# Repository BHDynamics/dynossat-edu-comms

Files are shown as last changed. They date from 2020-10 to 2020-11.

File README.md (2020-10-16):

# DynOSSAT-EDU-Comms (Communications System)
DynOSSAT-EDU is the first open source PocketQube educational kit compatible with CircuitPython and Arduino.

This plaform is equipped with all the necessary modules for the operation of a nanosatellite (PocketQube)
in Low Earth Orbit (LEO) that would serve as a device for teaching, training, and driving curiosity about the philosophy and technology related to NewSpace.

This repository contains the hardware files for the Communications system, the module responsible for handling radio communications.It integrates a long range LoRa module
to simulate LEO-Earth communications and a 2.4 GHz nRF52832 SoC to simulate LEO-LEO communications and to allow communication with mobile apps for teaching and simulation projects using Smartphones.

Hardware in this repository is licenced under **CERN OHL v1.2**.

## Technical details

- Based on HopeRF’s RFM96W 868 MHz LoRa module, pad-to-pad compatible with the 433 MHz RFM95W version
- Easily controlled through SPI bus
- Secondary 2.4 GHz SoC (SKB369) based on Nordic Semi nRF52832 that can act as an independent or redundant processor through I2C or SPI
- Female USB-C 2.0 connector for power and data logging (CH340E USB to UART bridge)

## Documentation

Available soon!

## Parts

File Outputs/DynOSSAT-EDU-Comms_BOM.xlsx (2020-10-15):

Item | Qty | Reference(s) | Value | Part Number | Footprint
1 | 2 | C1, C3 | 10uF |  | 0603 10uF X7R/X5R 10V or greater
2 | 3 | C2, C4, C8 | 100nF |  | 0402 100nF X7R/X5R 10V or greater
3 | 2 | C5, C6 | DNP | -
4 | 1 | D1 | LED | Device:LED | 0603 LED Red
5 | 1 | J1 | Main Bus PQBH40 | We don't have part numbers. Use generic connectors | Pin header male 1.27mm pitch 2x20 vertical SMD
6 | 1 | J2 | Main Bus PQBH40 | We don't have part numbers. Use generic connectors | Pin socket female 1.27mm pitch 2x20 vertical SMD
7 | 1 | J4 | Conn_Coaxial | U.FL-R-SMT-1(80) | 50 ohm U.FL Coaxial Connector
8 | 1 | J5 | USB_C_Receptacle_USB2.0 | U262-161N-4BVC11 | USB-C 2.0 connector - female socket
9 | 1 | J7 | Conn_01x09_Female | We don't have part numbers. Use generic connectors | Pin header male 2.54mm pitch 1x09 vertican Through Hole
10 | 1 | L1 | 0R |  | 0 ohm resistor 0402
11 | 2 | Q1, Q2 | DMG2305L | DMG2305UX-7 | P-Channel Power Mosfet
12 | 3 | R1, R5, R7 | 100k |  | 0402 100k 1%
13 | 2 | R2, R3 | 47k |  | 0402 47k 1%
14 | 2 | R4, R6 | 5.1k |  | 0402 5.1k 1%
15 | 1 | R8 | 510R |  | 0402 510R 1%
16 | 1 | SW1 | SW_Push | 1TS002G-1800-3500-CT | Push Button side mount
17 | 1 | U1 | ME6211C33 | ME6211C33M5G-N | 3V3 LDO SOT-23-5
18 | 1 | U2 | HopeRF RFM95 | RFM95W | 868 MHz LoRA module - global version
19 | 1 | U3 | Skylab SKB369 | SKB369 | Bluetooth Low Energy Module
20 | 1 | U4 | CH340E | CH340E | USB to UART Bridge IC SOIC-8
For passives (resistors, capacitors, etc) you may use any quality brand while meeting requirements

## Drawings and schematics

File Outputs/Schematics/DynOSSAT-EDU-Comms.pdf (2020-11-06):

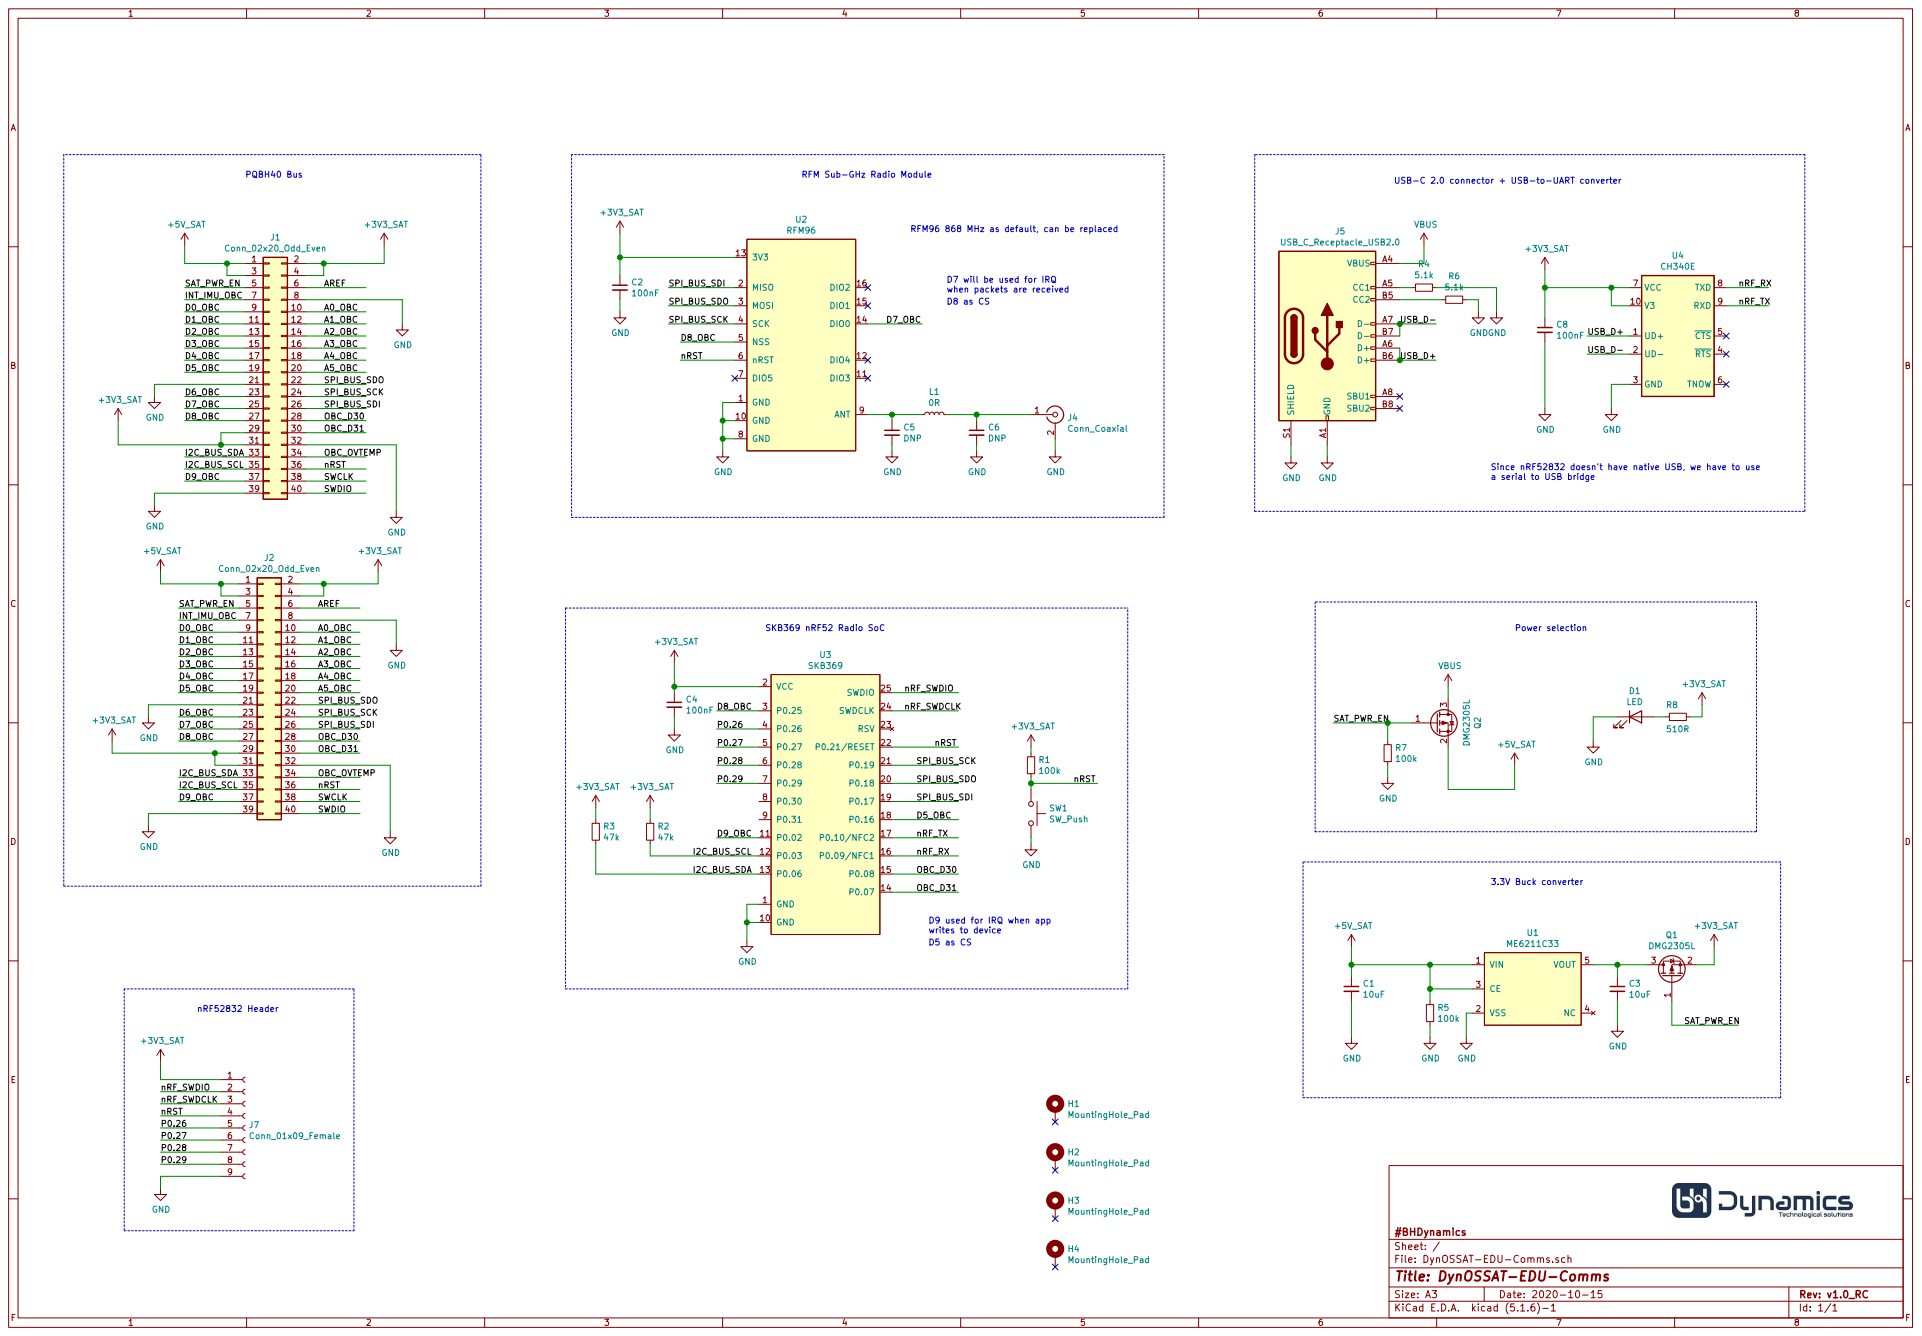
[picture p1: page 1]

USB-C 2.0 connector + USB-to-UART converter PQBH40 Bus

RFM96 868 MHz as default, can be replaced RFM Sub-GHz Radio Module SKB369 nRF52 Radio SoC

D7 will be used for IRQ
when packets are received
a serial to USB bridge D8 as CS

Since nRF52832 doesn't have native USB, we have to use

D5 as CS D9 used for IRQ when app writes to device

File: DynOSSAT-EDU-Comms.sch Sheet: / #BHDynamics

Id: 1/1 Title: DynOSSAT-EDU-Comms

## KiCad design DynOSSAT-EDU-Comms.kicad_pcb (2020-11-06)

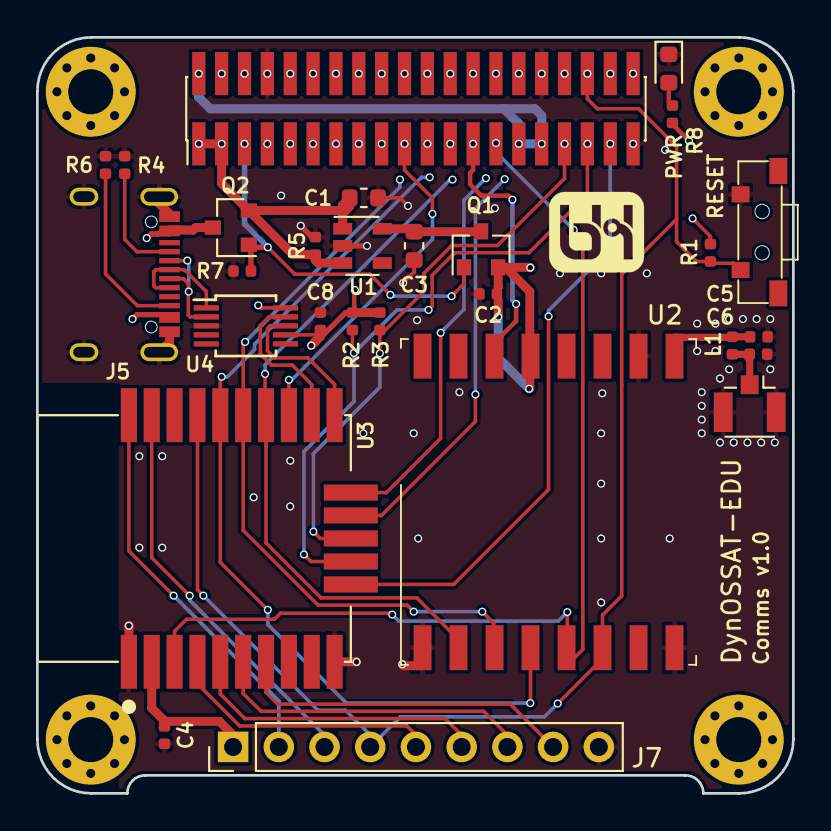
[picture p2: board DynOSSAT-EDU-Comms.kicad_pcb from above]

Board: 4 copper layers, 42.0 x 42.0 mm, 33 parts (1 on the bottom side), 50 nets.

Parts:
C1, C3: 10uF; C_0603_1608Metric
C2, C4, C8: 100nF; C_0402_1005Metric
C5, C6: DNP; C_0402_1005Metric
D1: LED; LED_0603_1608Metric
H1, H2, H3, H4: MountingHole_Pad; MountingHole_2.5mm_Pad_Via
J1: Conn_02x20_Odd_Even; PinHeader_2x20_P1.27mm_Vertical_SMD
J2: Conn_02x20_Odd_Even; PinSocket_2x20_P1.27mm_Vertical_SMD
J4: Conn_Coaxial; U.FL_Hirose_U.FL-R-SMT-1_Vertical
J5: USB_C_Receptacle_USB2.0; U262-161N-4BVC11
J7: Conn_01x09_Female; PinHeader_1x09_P2.54mm_Vertical
L1: 0R; L_0402_1005Metric
Q1, Q2: DMG2305L; SOT-23
R1, R5, R7: 100k; R_0402_1005Metric
R2, R3: 47k; R_0402_1005Metric
R4, R6: 5.1k; R_0402_1005Metric
R8: 510R; R_0402_1005Metric
SW1: SW_Push; 1TS002G-1800-3500-CT
U1: ME6211C33; SOT-23-5
U2: RFM96; HOPERF_RFM69HW
U3: SKB369; SKYLAB_SKB369
U4: CH340E; MSOP-10_3x3mm_P0.5mm

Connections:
+3V3_SAT: C2.1, C4.1, C8.1, J1.2, J1.4, J1.29, J1.31, J2.2, J2.4, J2.29, J2.31, J7.1, Q1.2, R1.1, R2.1, R3.1, R8.1, U2.13, U3.2, U4.7, U4.10
+5V_SAT: C1.1, J1.1, J1.3, J2.1, J2.3, Q2.2, R5.1, U1.1, U1.3
/A0_OBC: J1.10, J2.10
/A1_OBC: J1.12, J2.12
/A2_OBC: J1.14, J2.14
/A3_OBC: J1.16, J2.16
/A4_OBC: J1.18, J2.18
/A5_OBC: J1.20, J2.20
/AREF: J1.6, J2.6
/D0_OBC: J1.9, J2.9
/D1_OBC: J1.11, J2.11
/D2_OBC: J1.13, J2.13
/D3_OBC: J1.15, J2.15
/D4_OBC: J1.17, J2.17
/D5_OBC: J1.19, J2.19, U3.18
/D6_OBC: J1.23, J2.23
/D7_OBC: J1.25, J2.25, U2.14
/D8_OBC: J1.27, J2.27, U2.5, U3.3
/D9_OBC: J1.37, J2.37, U3.11
/I2C_BUS_SCL: J1.35, J2.35, R2.2, U3.12
/I2C_BUS_SDA: J1.33, J2.33, R3.2, U3.13
/INT_IMU_OBC: J1.7, J2.7
/OBC_D30: J1.28, J2.28, U3.15
/OBC_D31: J1.30, J2.30, U3.14
/OBC_OVTEMP: J1.34, J2.34
/P0.26: J7.5, U3.4
/P0.27: J7.6, U3.5
/P0.28: J7.7, U3.6
/P0.29: J7.8, U3.7
/SAT_PWR_EN: J1.5, J2.5, Q1.1, Q2.1, R7.1
/SPI_BUS_SCK: J1.24, J2.24, U2.4, U3.21
/SPI_BUS_SDI: J1.26, J2.26, U2.2, U3.19
/SPI_BUS_SDO: J1.22, J2.22, U2.3, U3.20
/SWCLK: J1.38, J2.38
/SWDIO: J1.40, J2.40
/USB_D+: J5.A6, J5.B6, U4.1
/USB_D-: J5.A7, J5.B7, U4.2
/nRF_RX: U3.16, U4.8
/nRF_SWDCLK: J7.3, U3.24
/nRF_SWDIO: J7.2, U3.25
/nRF_TX: U3.17, U4.9
/nRST: J1.36, J2.36, J7.4, R1.2, SW1.1, U2.6, U3.22
GND: C1.2, C2.2, C3.2, C4.2, C5.2, C6.2, C8.2, D1.1, J1.8, J1.21, J1.32, J1.39, J2.8, J2.21, J2.32, J2.39, J4.2, J5.A1, J5.A12, J5.B1, J5.B12, J5.S1, J7.9, R4.1, R5.2, R6.1, R7.2, SW1.2, U1.2, U2.1, U2.8, U2.10, U3.1, U3.10, U4.3
unnamed: C3.1, Q1.3, U1.5
unnamed: C5.1, L1.1, U2.9
unnamed: C6.1, J4.1, L1.2
unnamed: D1.2, R8.2
unnamed: J5.A5, R4.2
unnamed: J5.B5, R6.2
VBUS: J5.A4, J5.A9, J5.B4, J5.B9, Q2.3

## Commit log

2020-10-15 First commit, v1.0 RC
    [DynOSSAT-EDU-Comms-B_Cu.gbr, DynOSSAT-EDU-Comms-B_Fab.gbr, DynOSSAT-EDU-Comms-B_Mask.gbr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]
2020-11-06 Replace MISO/MOSI for SDI/SDO
    Update library to latest version
    [DynOSSAT-EDU-Comms-B_Cu.gbr, DynOSSAT-EDU-Comms-B_Fab.gbr, DynOSSAT-EDU-Comms-B_Mask.gbr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]
